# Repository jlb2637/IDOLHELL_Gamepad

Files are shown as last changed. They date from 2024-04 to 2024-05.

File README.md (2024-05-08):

# IDOLHELL_Gamepad
An Arduino based arcade style controller for my friends first game released on Steam!

IdolHellGamePadDone

The goal of this project was to be able to use arcade style joystick and buttons to play games on Steam, specifically IDOL HELL. A game created by some of my friends! Check it out here: https://store.steampowered.com/app/2067470/Idol_Hell/

### Main Parts List

|Part|Cost Estimate|Link to part|
| -- | --- | --- |
| Sanwa 24mm arcade pushbuttons | $10 | https://focusattack.com/sanwa-obsf-24mm-pushbutton-green/ |
| Sanwa 8-way arcade joystick | $23 | https://focusattack.com/sanwa-jlf-tp-8yt-joystick/ |
| Adafruit ItsyBitsy32U4 5v 16MHz | $10 | https://www.adafruit.com/product/3677 |
| Stranded Core wire, any color you like | $3 for a small spool | https://www.adafruit.com/product/2976 |
| 8 Countersunk 4-40 x 3/8" Screws | ~ $8 for a 50 pack | https://www.homedepot.com/p/Hillman-4-40-x-3-8-in-Phillips-Flat-Head-Machine-Screws-50-Pack-43071/204795006 |
| 4 #10-32 x 1/2" screws + matching nuts | $1.50 for an 8 pack with matching nuts | https://www.homedepot.com/p/10-32-x-1-2-in-Zinc-Plated-Combo-Round-Head-Machine-Screw-8-Pack-831201/317479055 |
| MatterHackers MH Build Series Pink | $21 per 1Kg Spool | https://www.matterhackers.com/store/l/175mm-pla-filament-pink-1-kg/sk/M81ZR601 |

 Optionally you can pick up proto-board and some resistors if you don't want to use internal pullup resistors, and your favorite Atmega32U4 board can likely be swapped in.

### Tools Required

Screwdriver (with flathead and philips bits)
3D Printer Access
Soldering Iron & accompanying tools (solder, sponge, etc.)

## Physical build

idolhellboxexploded

After pretending I didn't have to design the case for a long time, I finally got it done. Found a cool resource that talks about button layout that helped me break the wall and start working on it: https://www.slagcoin.com/joystick/layout.html

In the name of making things easier to print I decided to pull the logo on the cover off into its own separate files and glue the parts on. This meant there was a nice flat surface touching the print bed for everything.



## Electronics

IdolHellInternalWWalls

The electronics here are pretty simple, a microcontroller with 8 GPIO pins and USB/Serial capability is all you need!
Although it would be super cool to make a custom PCB, it just feels overkill for using a couple GPIO pins so I have hand soldered everything and used the internal pullup resistors on the microcontroller.
Specifically I am using an Adafruit itsy-bitsy 5V 16MHZ Atmega32u4. The code I've written should really work on any Atmega32u4 board, just remember to change the pins!

Here is an example of what your wiring with internal pullup resistors should look like:



In case you don't like them or don't have an mcu with internal pullup resistors, here is a schematic with them placed externally:



## Code

I went pretty simplistic with the code and it functions basically exactly like a macropad. This allows the buttons to easily be rebound and work on a large variety of games.
The Arduino keyboard.h library made this super simple too.

The one trick to remember is that since we are using internal pullup resistors to pull the disconnected state of each button high, we need to invert all of the inputs so they are active low(key pressed when shorted to ground).

###For the Future

I want to work on my case design a little more to make the parts maybe slot together. It would also be super cool to use other tools like a laser cutter to create enclosures out of things besides PLA.

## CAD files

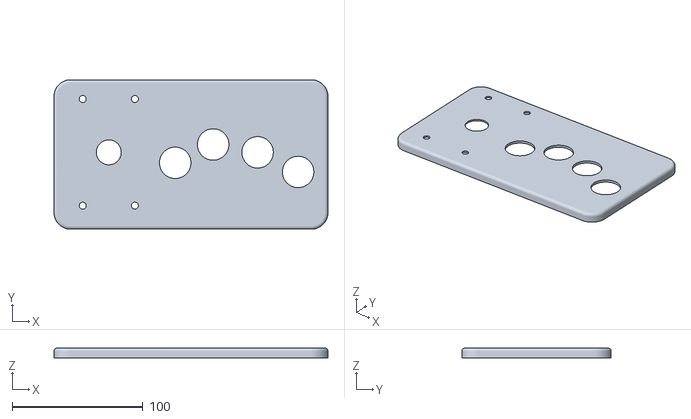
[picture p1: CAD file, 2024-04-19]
GamePadCoverFinal.stl
209.5 x 114.3 x 7.62

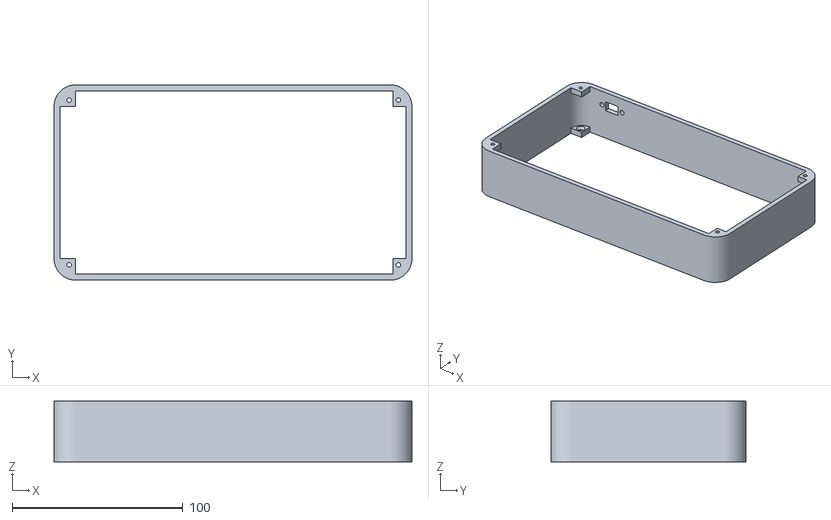
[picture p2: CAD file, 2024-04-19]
GamePadWalls.stl
209.5 x 114.3 x 35.6

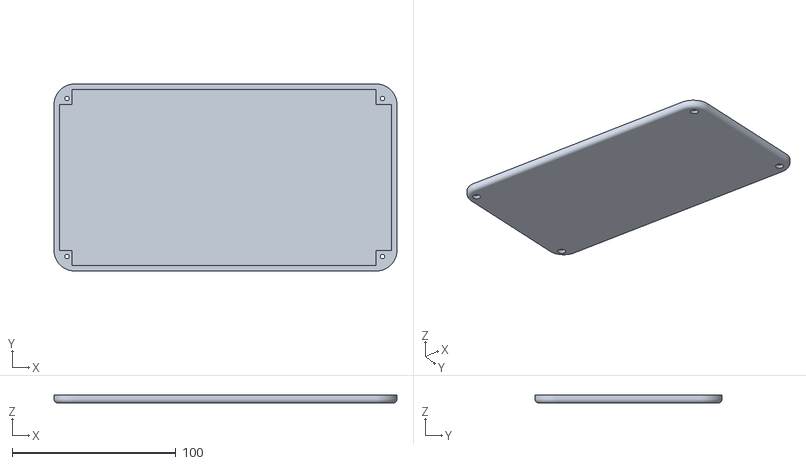
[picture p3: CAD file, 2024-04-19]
GamePadBase.stl
209.5 x 114.3 x 5.00

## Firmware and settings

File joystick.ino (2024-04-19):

#include <Keyboard.h>

// constants won't change. They're used here to set pin numbers:
const int dir1 = 7;
const int dir2 = 9;
const int dir3 = 10;
const int dir4 = 11;

const int button1 = 0;
const int button2 = 1;
const int button3 = 2;
const int button4 = 3;

//const int ledPin =  LED_BUILTIN;      // the number of the LED pin

// These are the debounce variables for the joystick
// jcs = joystick current state
// jps = joystick previous state
// bcs = button current state
// bps = button previous state
//joystick
int jcs1 = 0;
int jcs2 = 0;
int jcs3 = 0;
int jcs4 = 0;

int jps1 = 0;
int jps2 = 0;
int jps3 = 0;
int jps4 = 0;
//buttons
int bcs1 = 0;
int bcs2 = 0;
int bcs3 = 0;
int bcs4 = 0;

int bps1 = 0;
int bps2 = 0;
int bps3 = 0;
int bps4 = 0;

long lastDebounceTime = 0;
long debounceDelay = 50; //extend if input flickers

void setup() {

  //using internal pullup resistors to cut down on parts!
  // initialize the joystick input pins:
  pinMode(dir1, INPUT_PULLUP);
  pinMode(dir2, INPUT_PULLUP);
  pinMode(dir3, INPUT_PULLUP);
  pinMode(dir4, INPUT_PULLUP);
  //digitalWrite(ledPin, LOW);

  //initialize the button input pins
  pinMode(button1, INPUT_PULLUP);
  pinMode(button2, INPUT_PULLUP);
  pinMode(button3, INPUT_PULLUP);
  pinMode(button4, INPUT_PULLUP);

  Keyboard.begin();
}

void loop() {

    // read the state of the pushbutton value:
    jcs1 = digitalRead(dir1);
    jcs2 = digitalRead(dir2);
    jcs3 = digitalRead(dir3);
    jcs4 = digitalRead(dir4);

    bcs1 = digitalRead(button1);
    bcs2 = digitalRead(button2);
    bcs3 = digitalRead(button3);
    bcs4 = digitalRead(button4);

    if( (millis() - lastDebounceTime) > debounceDelay){
      //check if the joystick input changed
      //note that these are flipped because we are pulling out digital pins high and testing if they drop low

      //right
      if(jcs1 == 0){
          Keyboard.press('a');
      } else if (jcs1 == 1){
          Keyboard.release('a');
      }
      //left
      if(jcs2 == 0){
          Keyboard.press('d');
      } else if (jcs2 == 1){
          Keyboard.release('d');
      }
      //down
      if(jcs3 == 0){
          Keyboard.press('s');
      } else if (jcs3 == 1){
          Keyboard.release('s');
      }
      //up
      if(jcs4 == 0){
          Keyboard.press('w');
      } else if (jcs4 == 1){
          Keyboard.release('w');
      }

      //check if the button input changed
      //pinky button
      if(bcs1 == 0){
          Keyboard.press('q');
      } else if (bcs1 == 1){
          Keyboard.release('q');
      }
      //ring finger button
      if(bcs2 == 0){
          Keyboard.press('x');
      } else if (bcs2 == 1){
          Keyboard.release('x');
      }
      //middle finger
      if(bcs3 == 0){
          Keyboard.press(KEY_LEFT_SHIFT);
      } else if (bcs3 == 1){
          Keyboard.release(KEY_LEFT_SHIFT);
      }
      //pointer finger button
      if(bcs4 == 0){
          Keyboard.press('z');
      } else if (bcs4 == 1){
          Keyboard.release('z');
      }
//lshift, is focus move, z is shoot, x is bomb

      lastDebounceTime = millis();

      //save current state to the previous state since the next thing we do is read a new current state
      jps1 = jcs1;
      jps2 = jcs2;
      jps3 = jcs3;
      jps4 = jcs4;

      bps1 = bcs1;
      bps2 = bcs2;
      bps3 = bcs3;
      bps4 = bcs4;
    }
}

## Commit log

2023-05-16 Add files via upload
    Joystick working on Arduino Micro, Need to add the buttons and finalize but I want to finish the physical design/build first
2024-04-17 3D Printable top plate
    Working on the rest after I fit the components in to see how tall I need the body to be
    [CoverFinal.stl]
2024-04-19 Update and rename joystickv1.ino to joystick.ino
    Updated the pin numbers, added the extra buttons, and changed resistors to internal pullup
2024-04-19 Delete CoverFinal.stl
    Adding back in the right one in a minute
    [CoverFinal.stl]
2024-04-19 Add files via upload
    All of the 3d printable enclosure parts, excluding the detail plates
    [GamePadBase.stl, GamePadCoverFinal.stl, GamePadWalls.stl]
2024-04-28 Update README.md
    Attempt one at making a BOM table
2024-05-03 Update README.md
    Added filament to BOM
